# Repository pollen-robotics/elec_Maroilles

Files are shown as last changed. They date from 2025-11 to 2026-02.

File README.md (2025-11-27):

# "Maroilles" Electronic Board

"elec_maroilles" is USB 2.0 hub built with lockable USB connectors. It provides also Dynamixel TTL and Dynamixel RS485 converters and the associated connectors for Reachy 2's grippers and antennas.

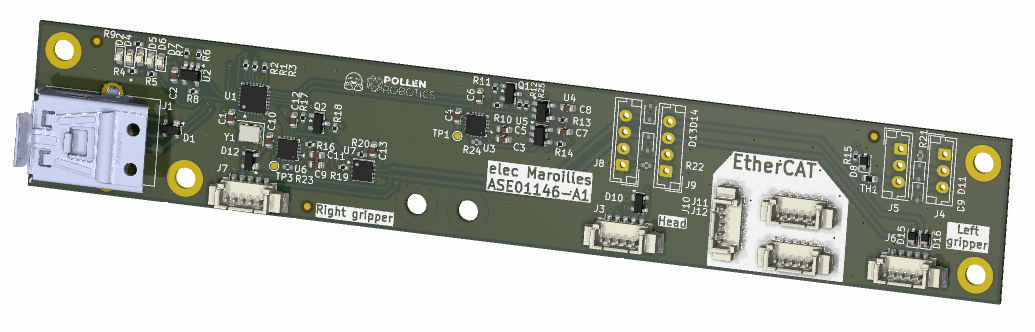
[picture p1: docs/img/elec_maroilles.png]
3d view


## Basically
 - Designed with KiCAD 9.

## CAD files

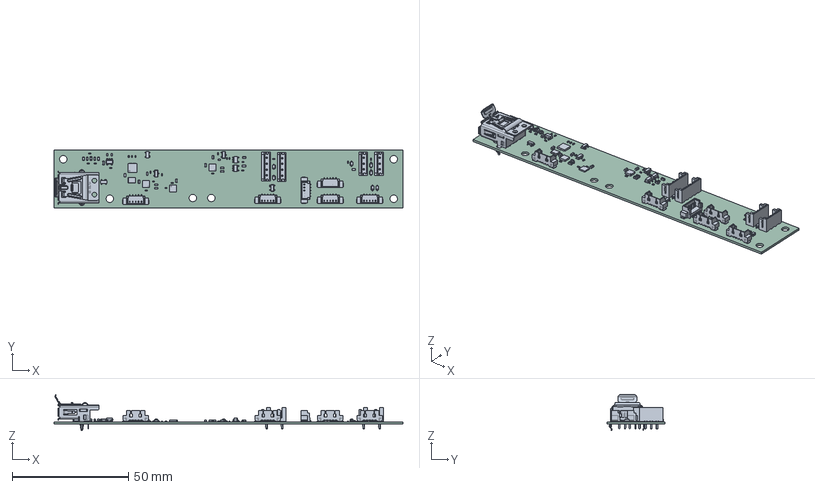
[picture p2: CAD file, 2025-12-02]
fab/elec_maroilles.step
150.0 x 25.0 x 15.6 mm
Molex_PicoBlade_53398-0571_1x05-1MP_P1.25mm_Vertical x 6
C_0603_1608Metric x 13
JST_EH_B3B-EH-A_1x03_P2.50mm_Vertical x 2
WQFN-16-1EP_3x3mm_P0.5mm_EP1.6x1.6mm x 3
R_0402_1005Metric x 25
LUSBA11100--3DModel-STEP-533217
R_0603_1608Metric
D_SOD-323 x 7
Texas_RTW_WQFN-24-1EP_4x4mm_P0.5mm_EP2.7x2.7mm
SOT-143 x 3
SOT-23-5 x 3
JST_EH_B4B-EH-A_1x04_P2.50mm_Vertical x 2
LED_0603_1608Metric x 5
SOT-23 x 2
Crystal_SMD_3225-4Pin_3.2x2.5mm
DFN-8-1EP_3x3mm_P0.65mm_EP1.5x2.25mm
elec_maroilles_PCB

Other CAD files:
fab/ASE01146-A1_elec_maroilles_STEP.step

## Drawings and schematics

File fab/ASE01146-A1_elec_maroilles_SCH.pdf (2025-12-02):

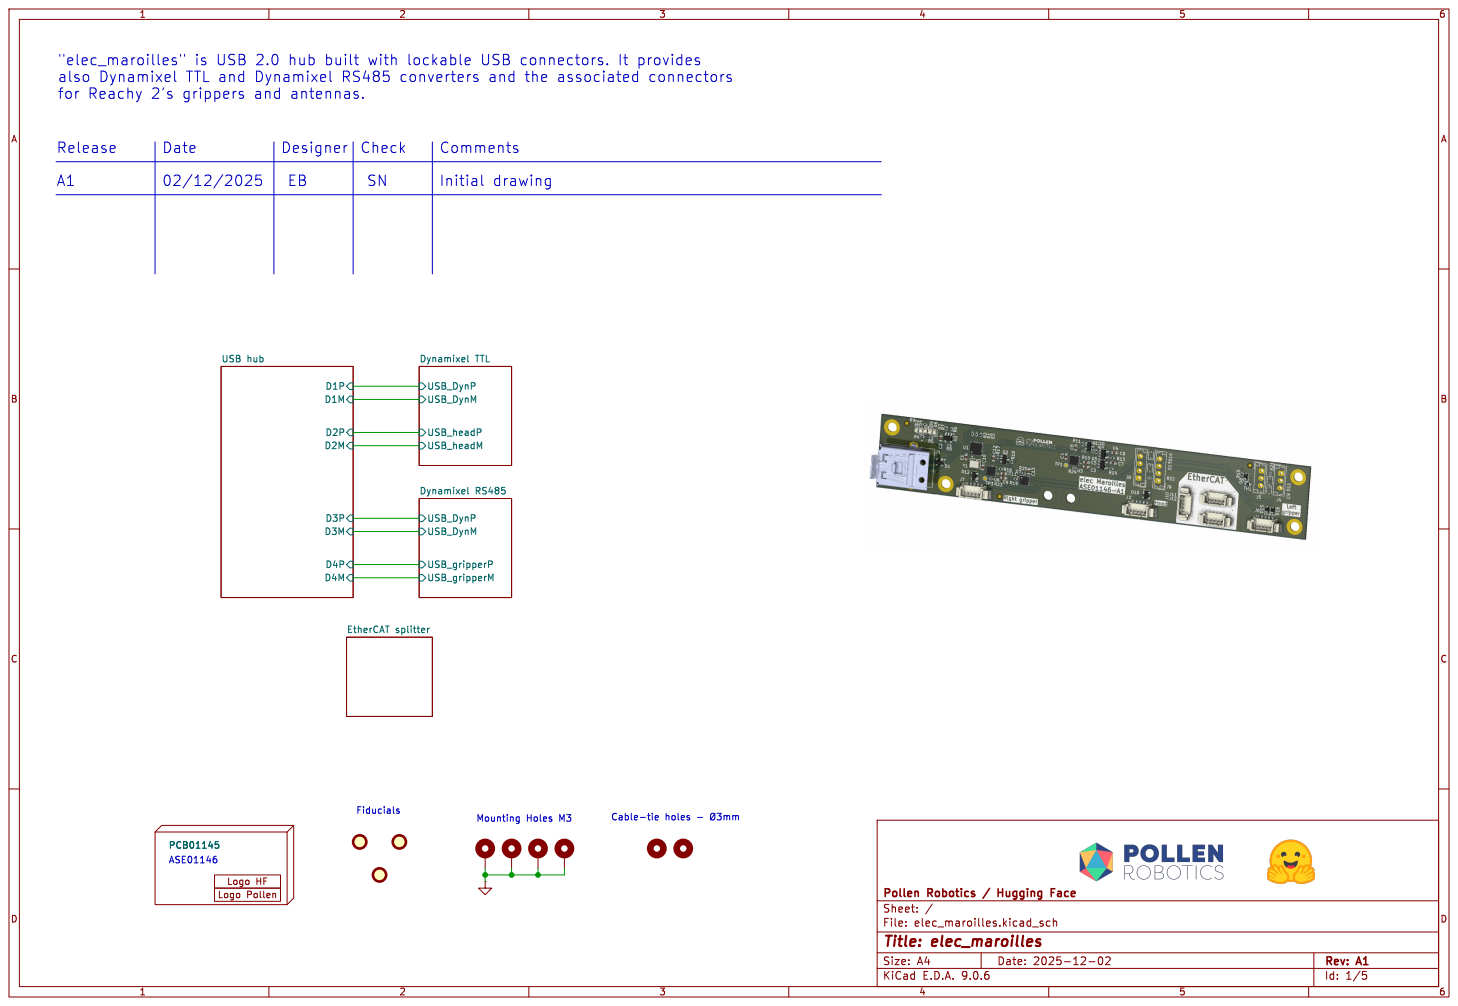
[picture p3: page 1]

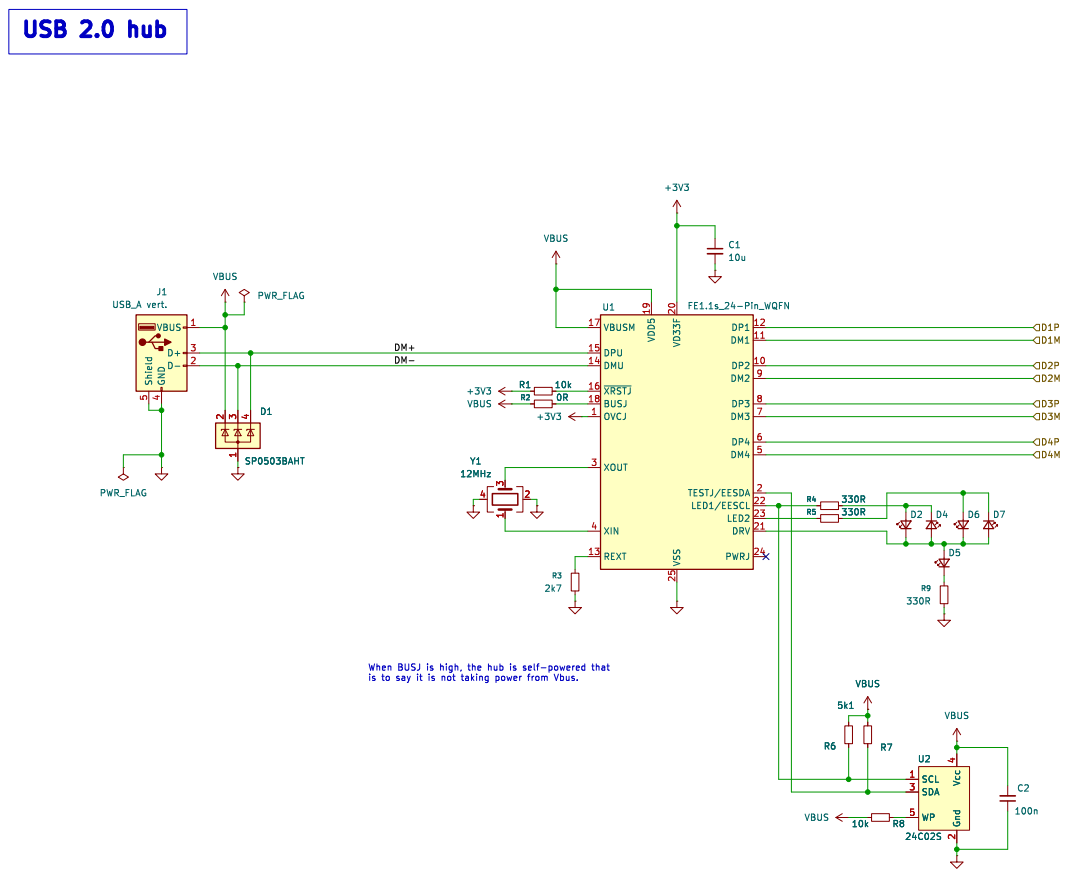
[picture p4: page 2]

DM+ DM- USB 2.0 hub

is to say it is not taking power from Vbus. D1 SP0503BAHT

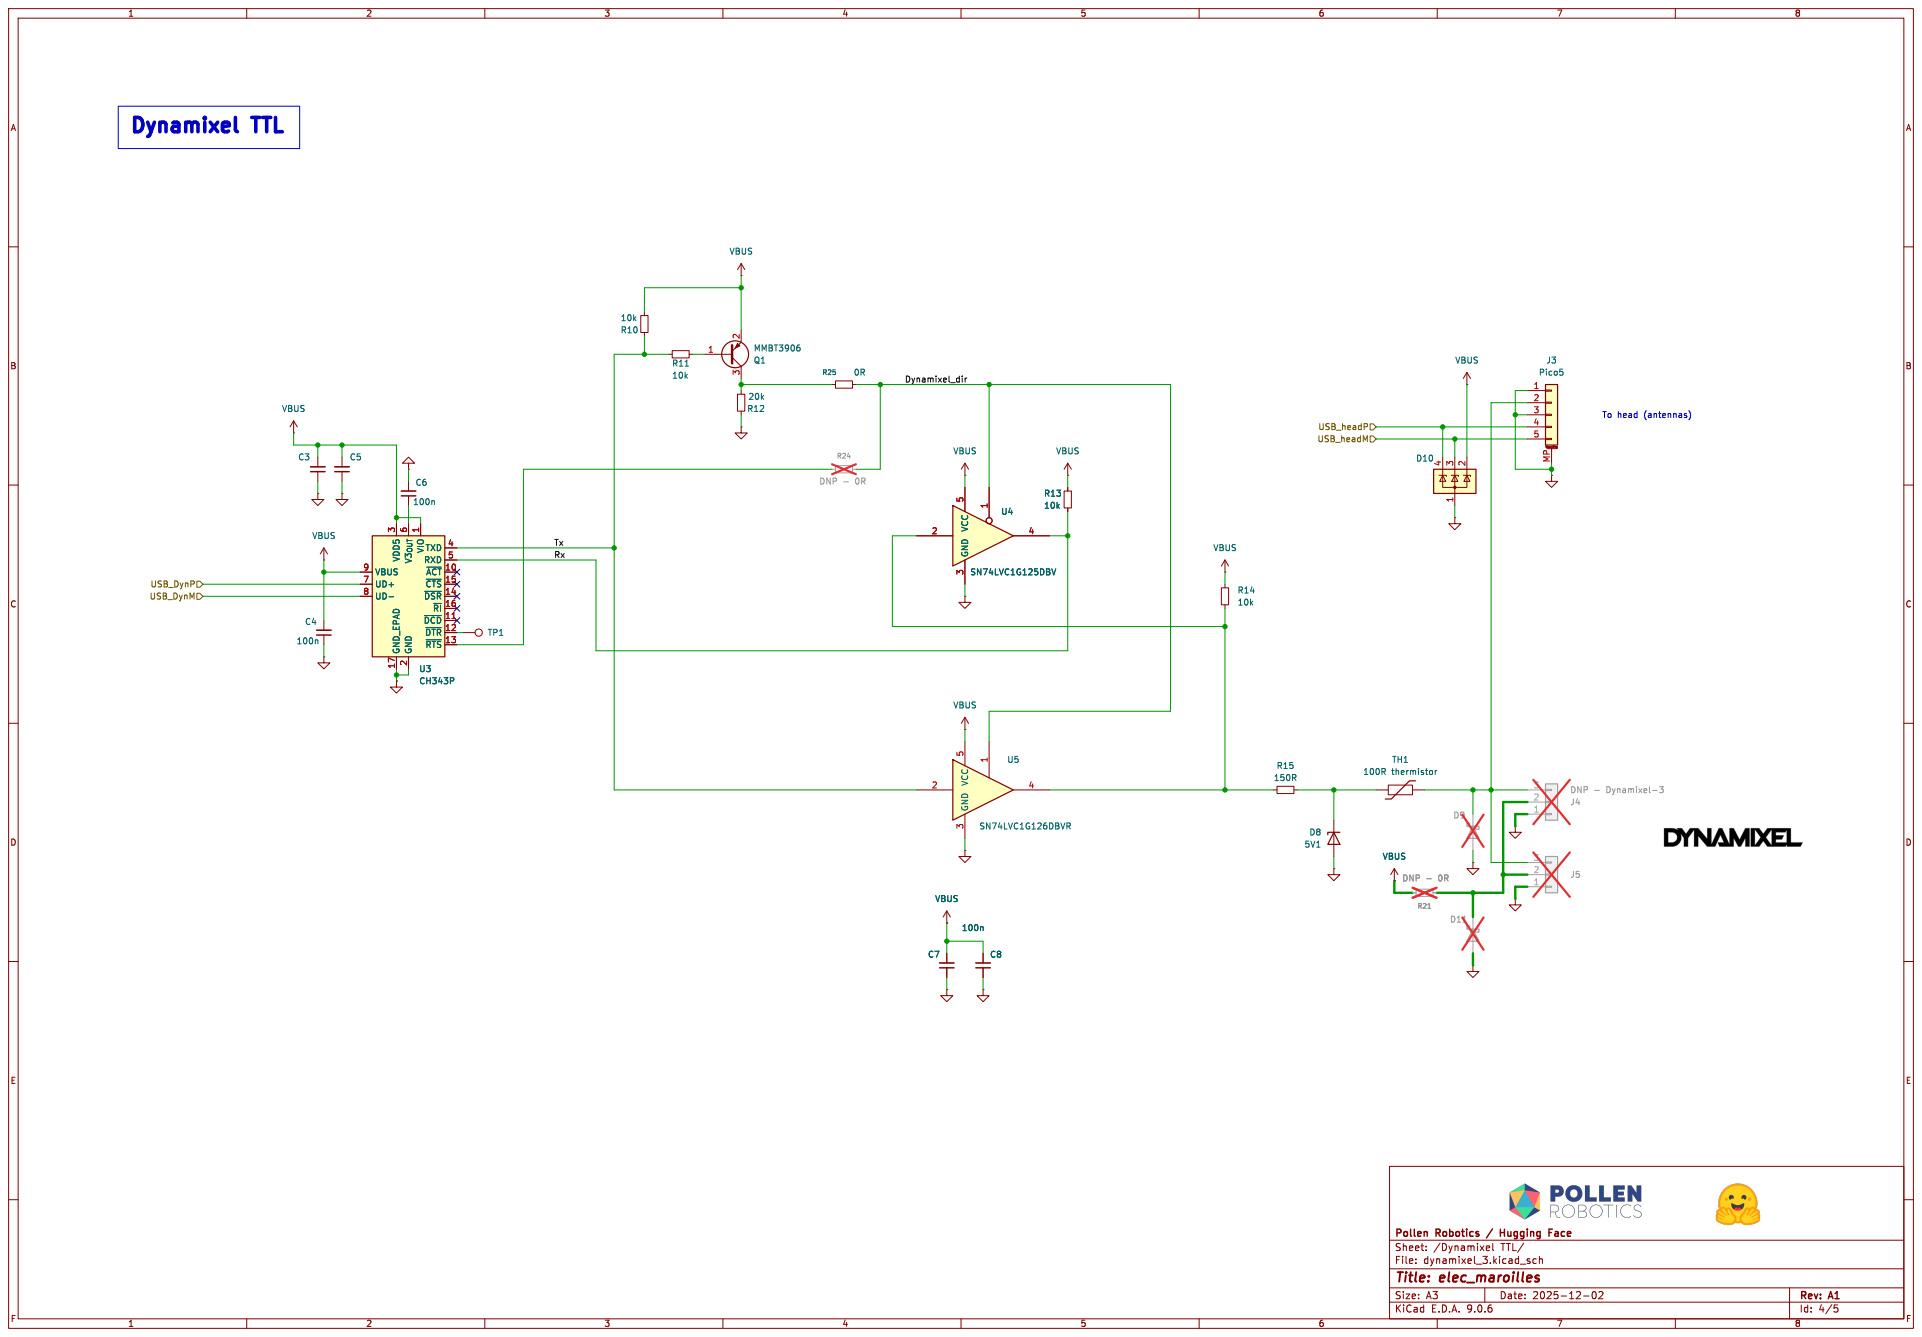
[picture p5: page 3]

1 TXD 4 RXD 5 ~{ACT} 10 ~{CTS} 15 ~{DSR} 14 ~{RI} 16 ~{DCD} 11 ~{DTR} 12 ~{RTS} 13 U3 CH343P

1 TXD 4 RXD 5 ~{ACT} 10 ~{CTS} 15 ~{DSR} 14 ~{RI} 16 ~{DCD} 11 ~{DTR} 12 ~{RTS} 13 VBUS C7

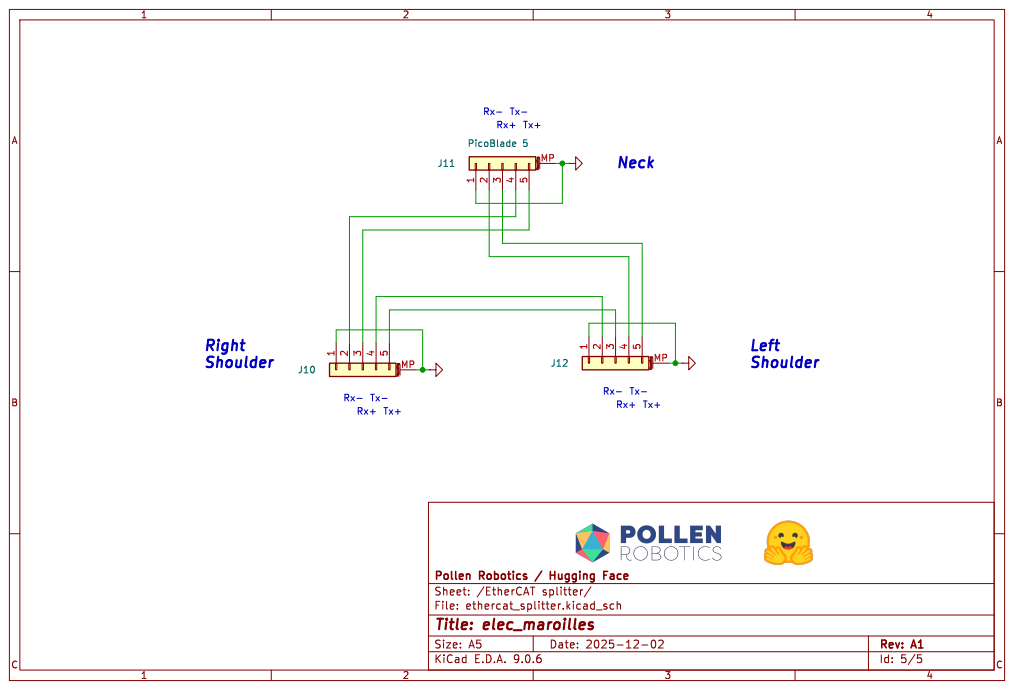
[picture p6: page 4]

5 MP J11 PicoBlade 5 Tx+ Tx+ Left

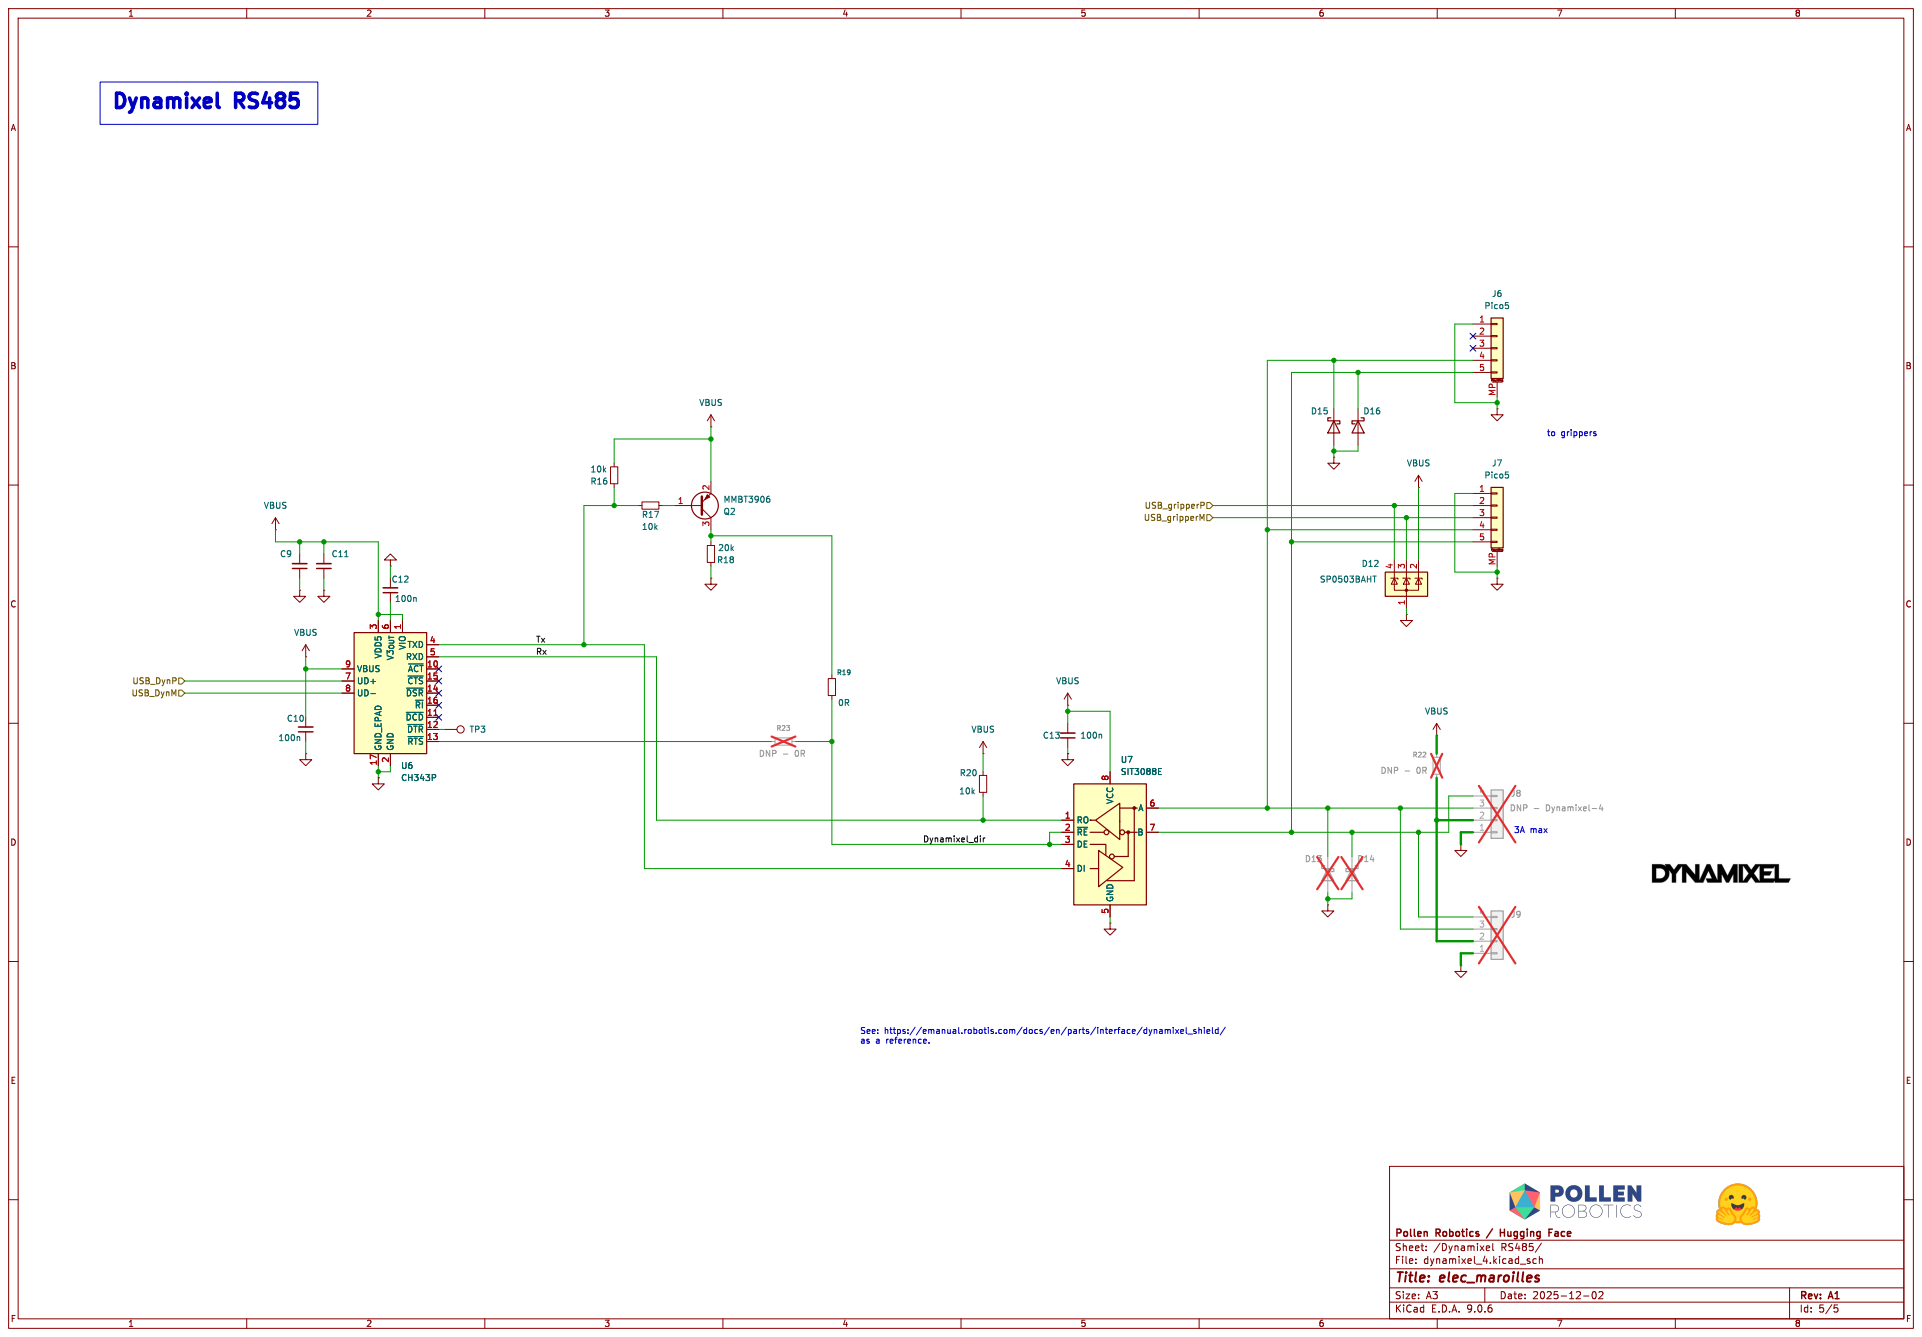
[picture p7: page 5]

1 TXD 4 RXD 5 ~{ACT} 10 ~{CTS} 15 ~{DSR} 14 ~{RI} 16 ~{DCD} 11 ~{DTR} 12 ~{RTS} 13 U6 CH343P D13 D14 USB_gripperP

1 TXD 4 RXD 5 ~{ACT} 10 ~{CTS} 15 ~{DSR} 14 ~{RI} 16 ~{DCD} 11 ~{DTR} 12 ~{RTS} 13 U7SIT3088E RO 1 ~{RE} 2 DE 3 DI 4 VCC

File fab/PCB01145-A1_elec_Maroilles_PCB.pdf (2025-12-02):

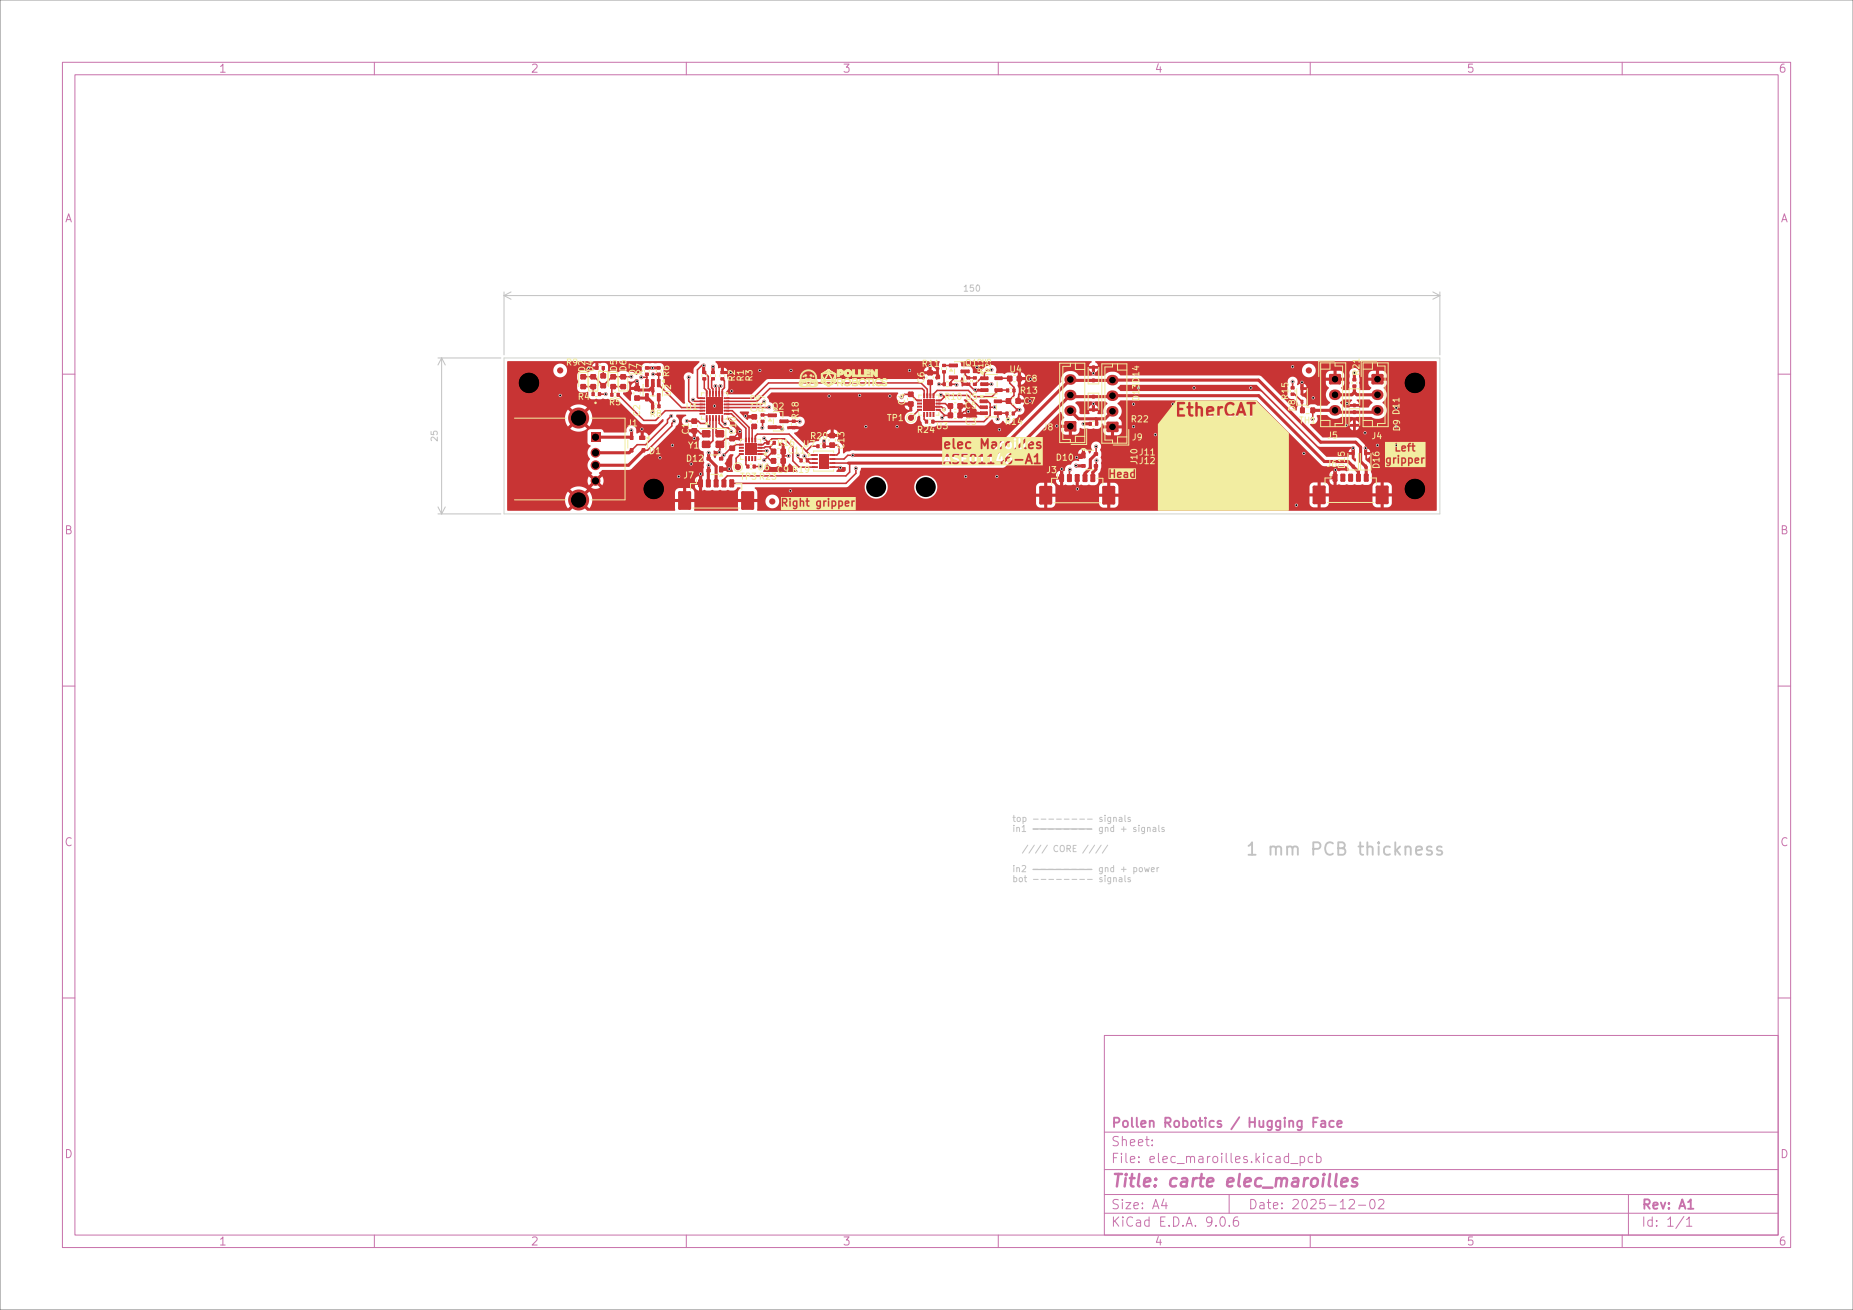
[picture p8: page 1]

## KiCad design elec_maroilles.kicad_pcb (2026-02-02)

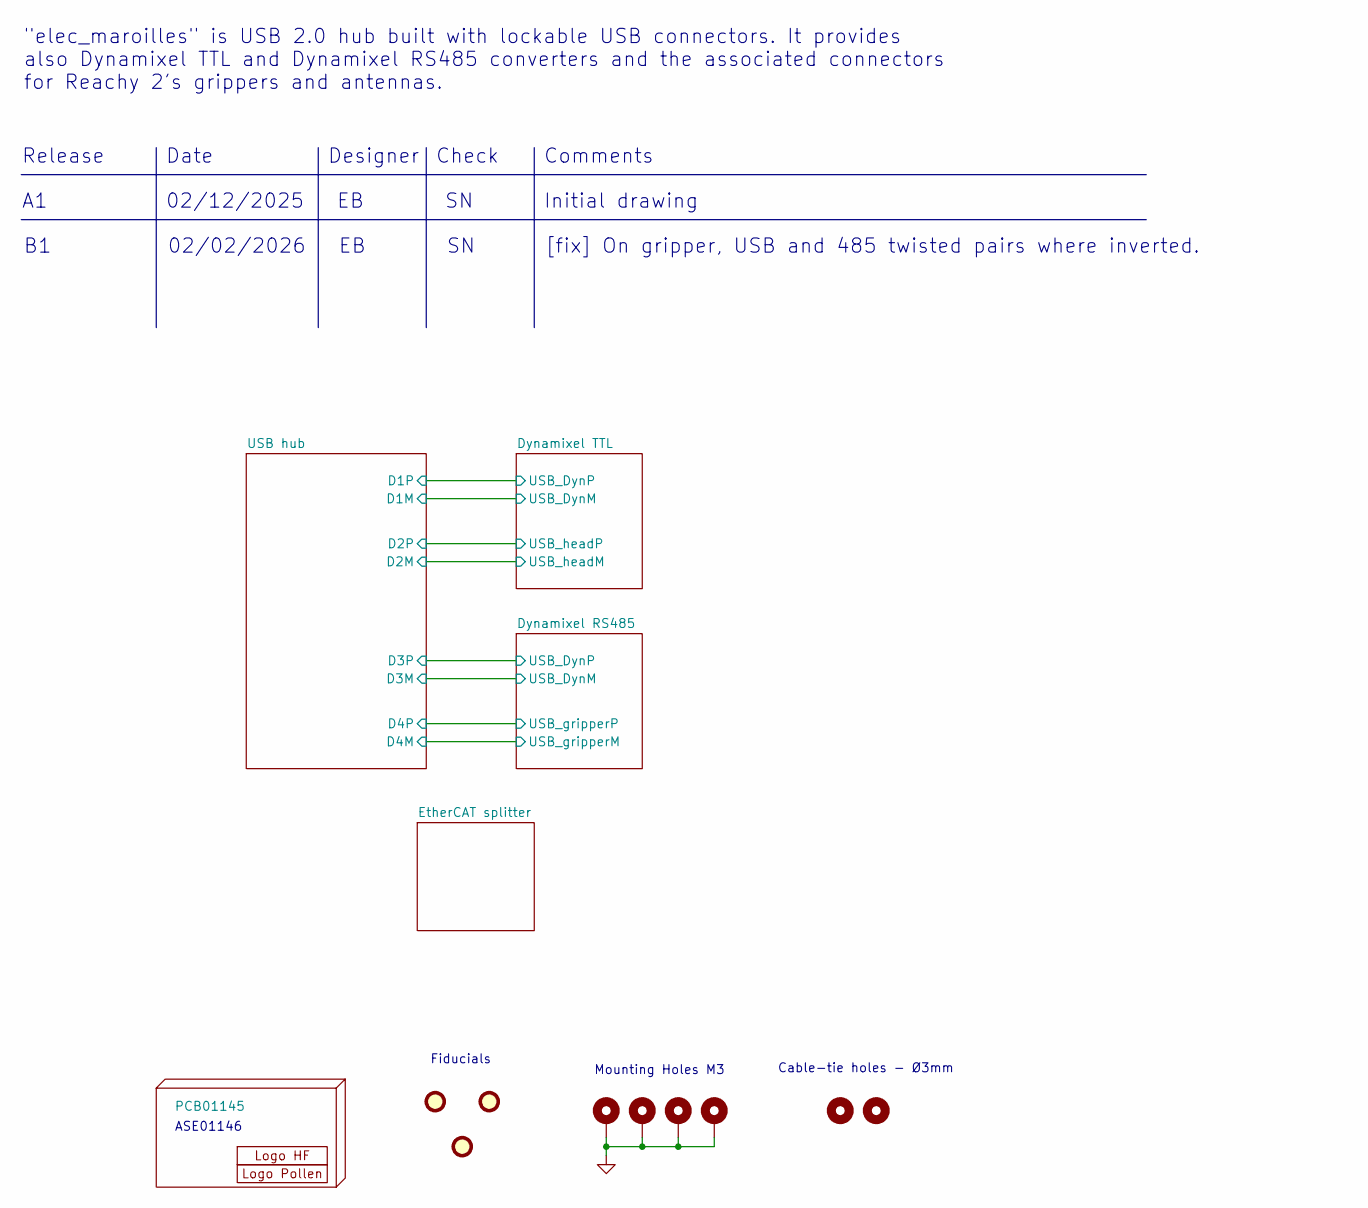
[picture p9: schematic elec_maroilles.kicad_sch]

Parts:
FID1, FID2, FID3: DNP Fiducial; Fiducial_1mm_Mask2mm
H1: PCB01145
H2: Logo HF 2025; Logo_HF_2025
H3: DNP Logo Pollen 2021; Logo_Pollen_2021_sq
H4, H5, H6, H7: MountingHole_Pad; MountingHole_3.2mm_M3_ISO7380_Pad_TopBottom
H10, H11: MountingHole_Pad; MountingHole_3.2mm_M3

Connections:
GND: H4.1, H5.1, H6.1, H7.1; also elsewhere on the board

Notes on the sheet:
Mounting Holes M3
Date
Check
Release
Fiducials
ASE01146
Cable-tie holes - Ø3mm
Initial drawing
[fix] On gripper, USB and 485 twisted pairs where inverted.
"elec_maroilles" is USB 2.0 hub built with lockable USB connectors. It provides also Dynamixel TTL and Dynamixel RS485 converters and the associated connectors for Reachy 2's grippers and antennas.
02/02/2026
Designer
Comments
02/12/2025

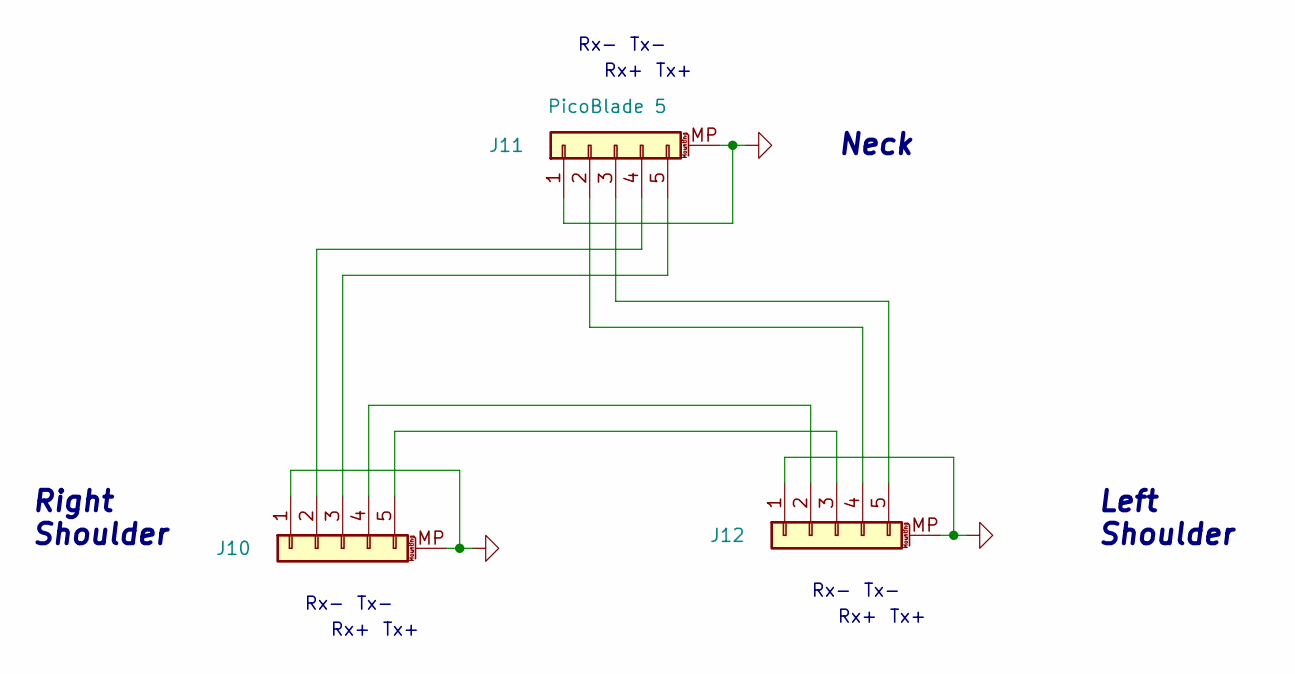
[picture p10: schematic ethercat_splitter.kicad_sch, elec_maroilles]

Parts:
J10, J11, J12: PicoBlade 5; Molex_PicoBlade_53398-0571_1x05-1MP_P1.25mm_Vertical; LCSC Part C504986

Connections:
GND: J10.1, J10.MP (MountPin), J11.1, J11.MP (MountPin), J12.1, J12.MP (MountPin); also elsewhere on the board
unnamed: J10.2, J11.4
unnamed: J10.3, J11.5
unnamed: J10.4, J12.2
unnamed: J10.5, J12.3
unnamed: J11.2, J12.4
unnamed: J11.3, J12.5

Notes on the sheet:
Rx-
Tx-
Right Shoulder
Rx+
Left Shoulder
Neck
Tx+

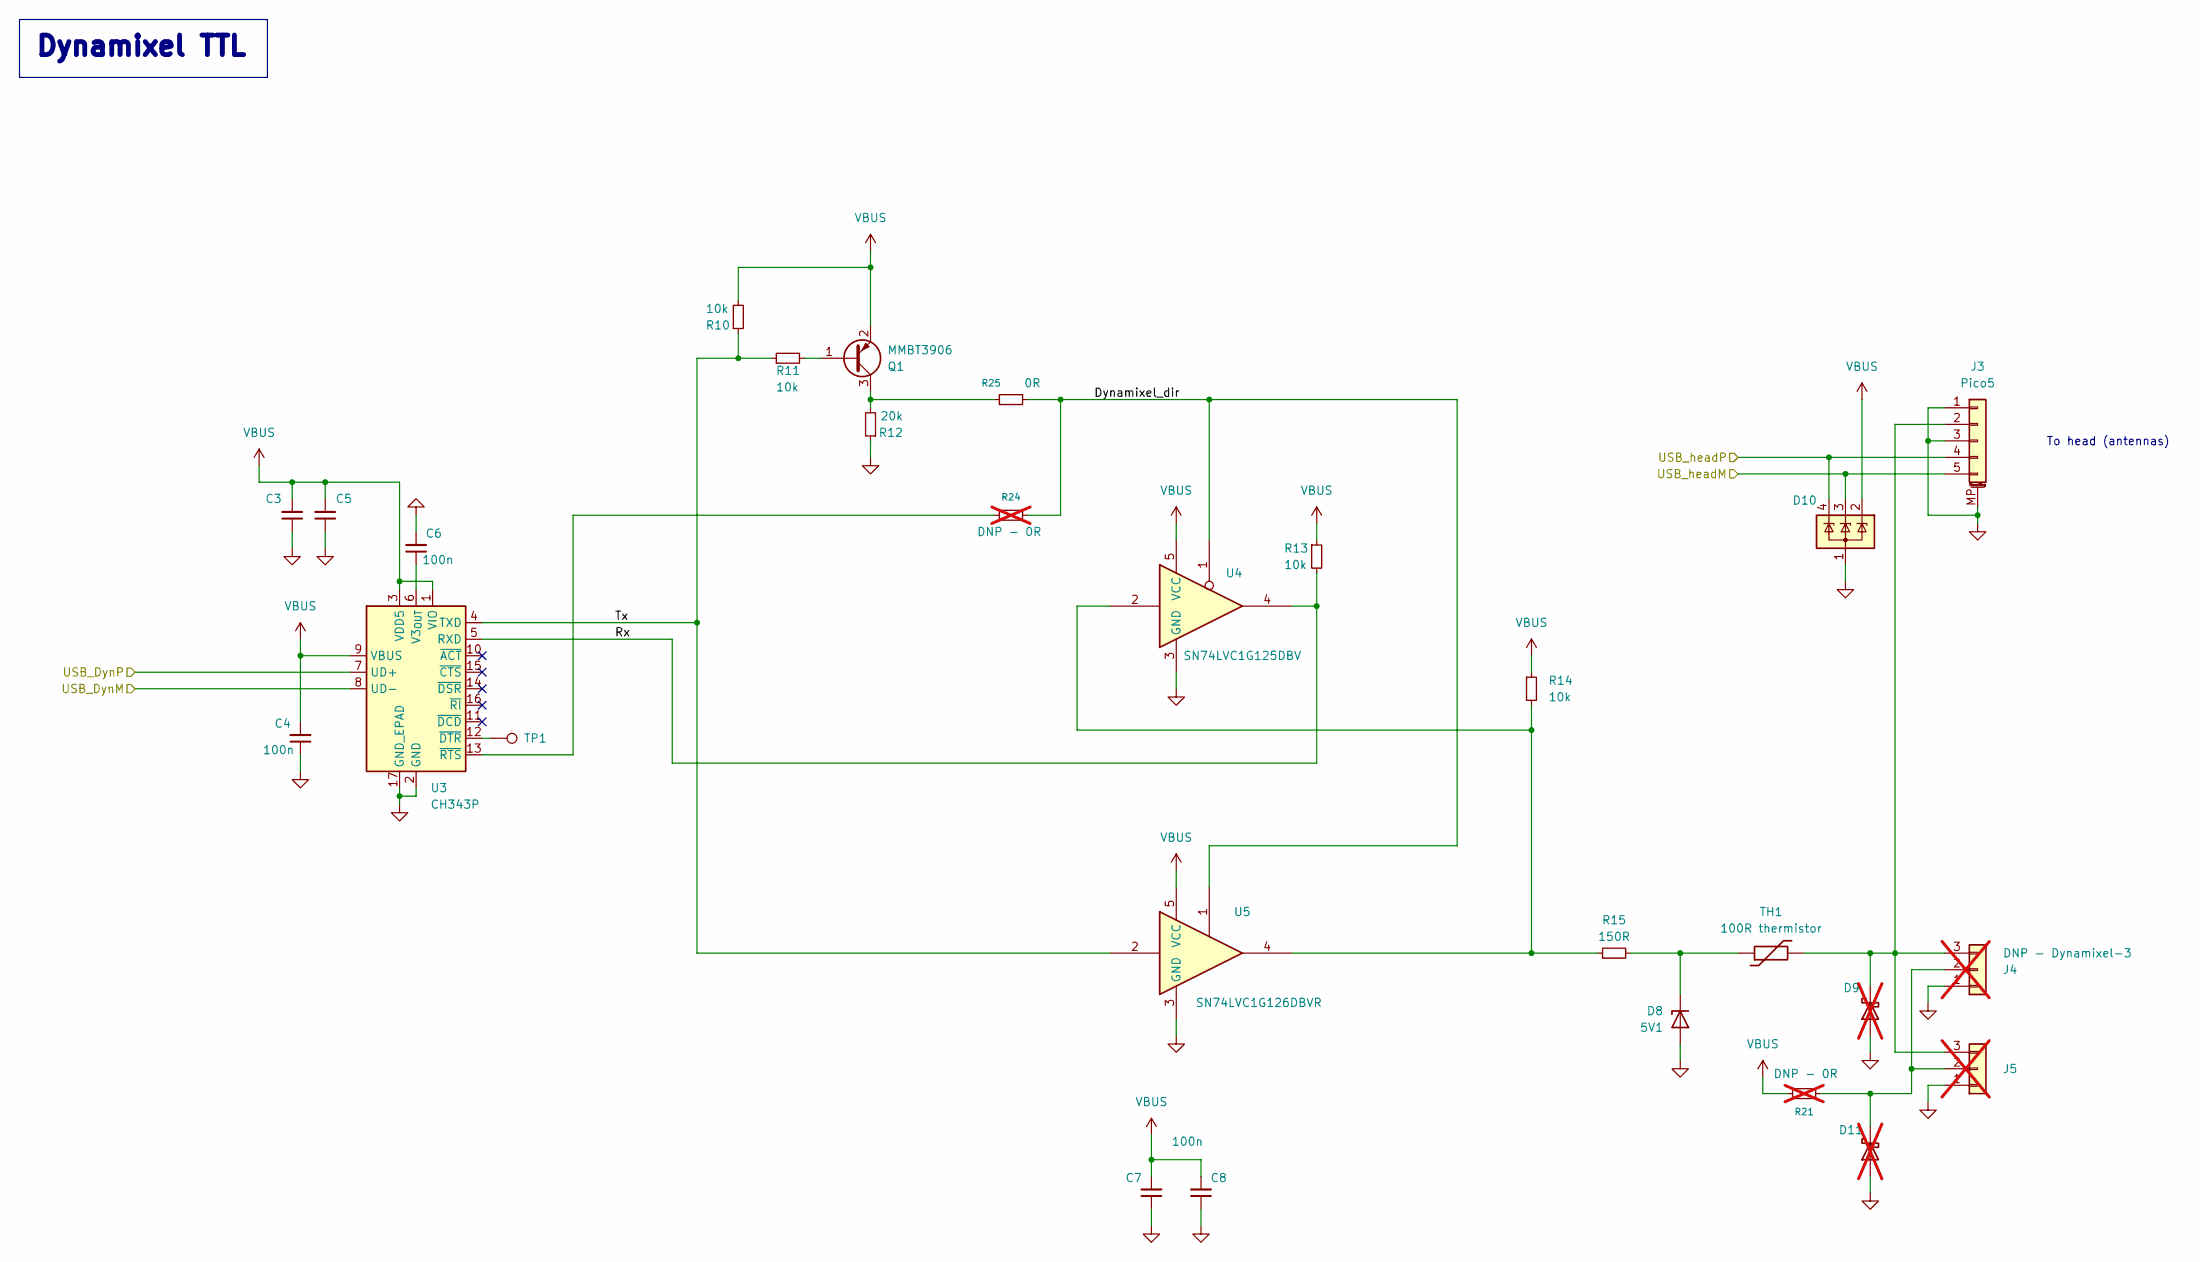
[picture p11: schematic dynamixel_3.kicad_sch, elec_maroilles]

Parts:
C3, C5: 1uF-6V3; C_0603_1608Metric; LCSC Part C1592
C4, C6, C7, C8: 100n; C_0603_1608Metric; LCSC Part C85864
D8: 5V1; D_SOD-323; LCSC Part C151348
D9, D11: DNP - B5819WS; D_SOD-323; LCSC Part C78734; not fitted
D10: SP0503BAHT; SOT-143; LCSC Part C41364459
J3: Pico5; Molex_PicoBlade_53398-0571_1x05-1MP_P1.25mm_Vertical; LCSC Part C504986
J4, J5: DNP - Dynamixel-3; JST_EH_B3B-EH-A_1x03_P2.50mm_Vertical; LCSC Part C160259; not fitted
Q1: MMBT3906; SOT-23; LCSC Part C727128
R10, R11, R13, R14: 10k; R_0402_1005Metric; LCSC Part C25744
R12: 20k; R_0402_1005Metric; LCSC Part C2906867
R15: 150R; R_0402_1005Metric; LCSC Part C138054
R21: DNP - 0R; R_0402_1005Metric; not fitted
R24: DNP - 0R; R_0402_1005Metric; LCSC Part C17168; not fitted
R25: 0R; R_0402_1005Metric; LCSC Part C17168
TH1: 100R thermistor; R_0603_1608Metric; LCSC Part C913703
TP1: TestPoint; TestPoint_Pad_D1.0mm
U3: CH343P; WCH_QFN-16-1EP_3x3mm_P0.5mm_EP1.8x1.8mm; LCSC Part C2846043
U4: SN74LVC1G125DBV; SOT-23-5; LCSC Part C23654
U5: SN74LVC1G126DBVR; SOT-23-5; LCSC Part C7834

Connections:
/Dynamixel TTL/Dynamixel_dir: R24.2, R25.2, U4.1, U5.1
/Dynamixel TTL/Rx: R13.2, U3.5 (RXD), U4.4
/Dynamixel TTL/Tx: R10.1, R11.1, U3.4 (TXD), U5.2
/Dynamixel TTL/USB_DynM: U3.8 (UD-); also elsewhere on the board
/Dynamixel TTL/USB_DynP: U3.7 (UD+); also elsewhere on the board
/Dynamixel TTL/USB_headM: D10.3 (K), J3.5; also elsewhere on the board
/Dynamixel TTL/USB_headP: D10.4 (K), J3.4; also elsewhere on the board
GND: C3.1, C4.1, C5.1, C6.2, C7.1, C8.1, D8.2 (A), D9.2 (A), D10.1 (A), D11.2 (A), J3.1, J3.3, J3.MP (MountPin), J4.1, J5.1, R12.1, U3.2 (GND), U3.17 (GND_EPAD), U4.3 (GND), U5.3 (GND); also elsewhere on the board
unnamed: D8.1 (K), R15.2, TH1.1
unnamed: D9.1 (K), J3.2, J4.3, J5.3, TH1.2
unnamed: D11.1 (K), J4.2, J5.2, R21.2
unnamed: Q1.1 (B), R11.2
unnamed: Q1.3 (C), R12.2, R25.1
unnamed: R14.2, R15.1, U4.2, U5.4
unnamed: C6.1, U3.6 (V3_{OUT})
unnamed: TP1.1, U3.12 (~DTR)
unnamed: R24.1, U3.13 (~RTS)
VBUS: C3.2, C4.2, C5.2, C7.2, C8.2, D10.2 (K), Q1.2 (E), R10.2, R13.1, R14.1, R21.1, U3.1 (VIO), U3.3 (VDD5), U3.9 (VBUS), U4.5 (VCC), U5.5 (VCC); also elsewhere on the board

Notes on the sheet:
To head (antennas)
Dynamixel TTL

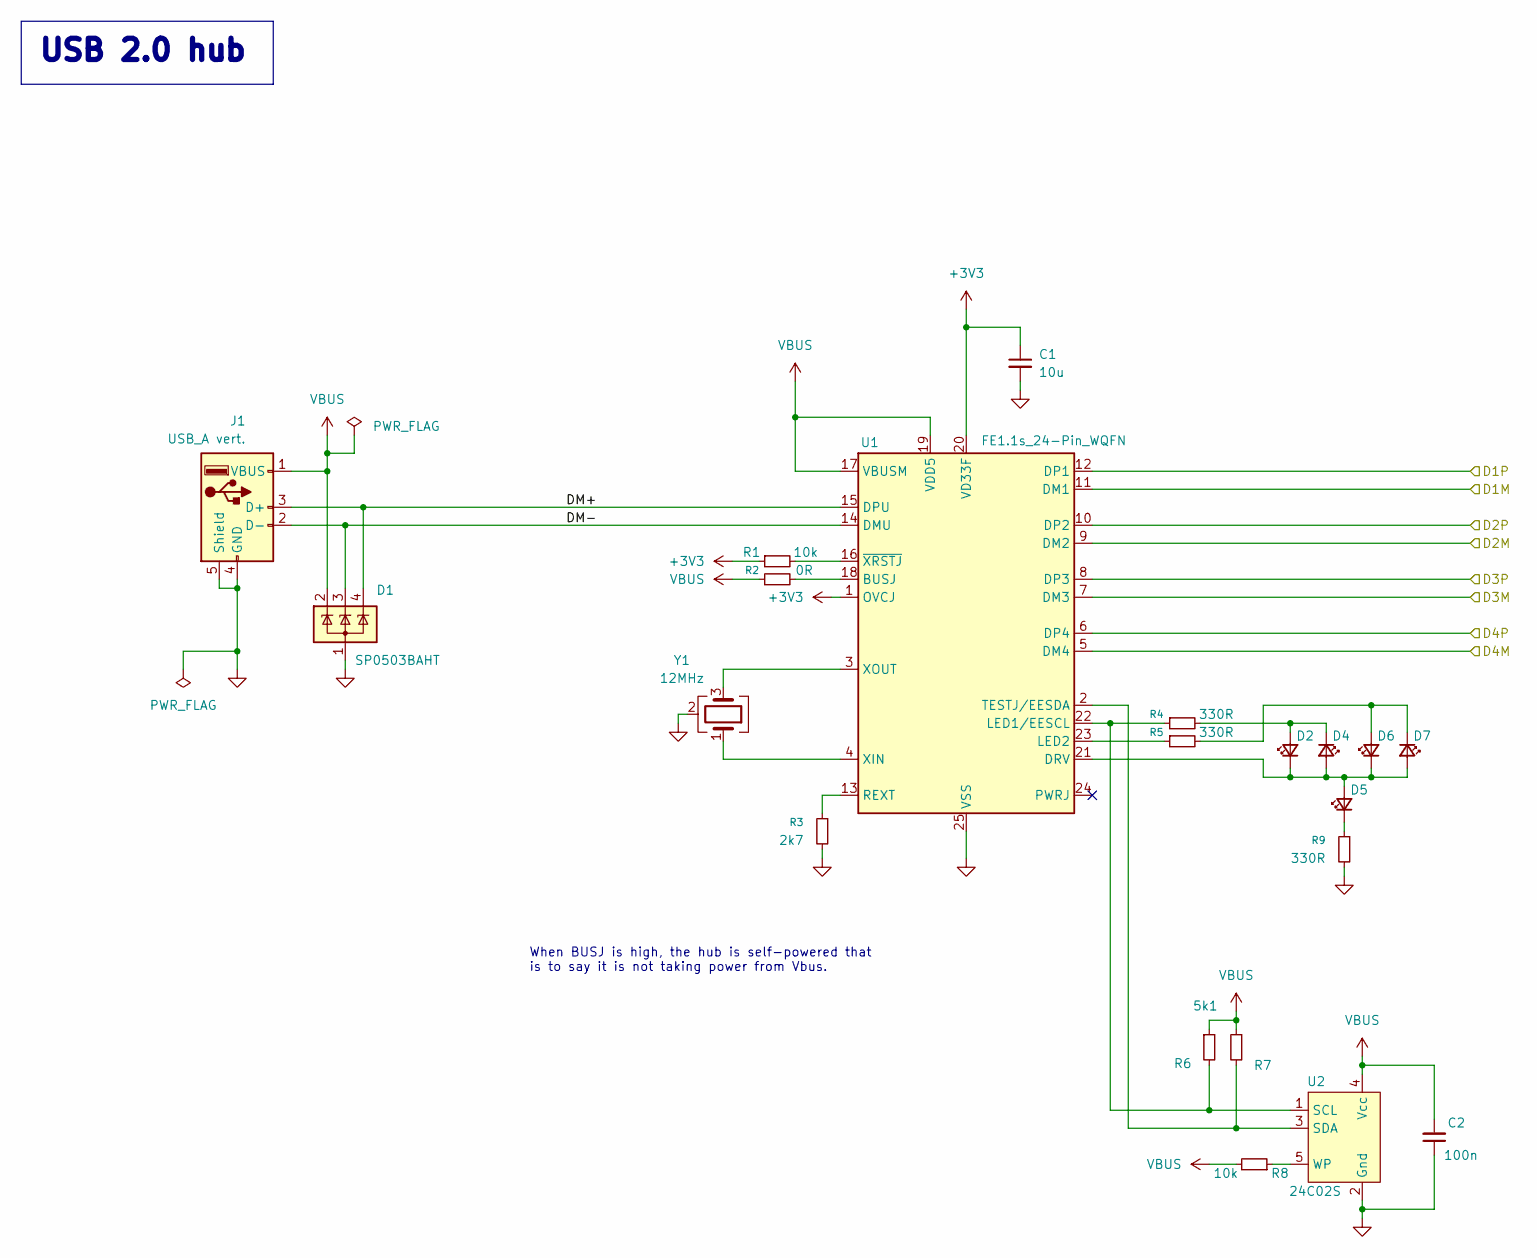
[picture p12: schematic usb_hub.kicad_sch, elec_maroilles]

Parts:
C1: 10u; C_0603_1608Metric; LCSC Part C1691
C2: 100n; C_0603_1608Metric; LCSC Part C85864
D1: SP0503BAHT; SOT-143; LCSC Part C41364459
D2, D6: LED_Small; LED_0603_1608Metric; LCSC Part C19171301
D4, D7: LED_Small; LED_0603_1608Metric; LCSC Part C84263
D5: LED_Small; LED_0603_1608Metric; LCSC Part C7429915
J1: USB_A vert.; Amphenol_LUSBA11100; LCSC Part C3197751
R1, R8: 10k; R_0402_1005Metric; LCSC Part C25744
R2: 0R; R_0402_1005Metric; LCSC Part C17168
R3: 2k7; R_0402_1005Metric; LCSC Part C138017
R4, R5, R9: 330R; R_0402_1005Metric; LCSC Part C105875
R6, R7: 5k1; R_0402_1005Metric; LCSC Part C25905
U1: FE1.1s_24-Pin_WQFN; WQFN-24-1EP_4x4mm_P0.5mm_EP2.6x2.6mm; LCSC Part C6776948
U2: 24C02S; SOT-23-5; LCSC Part C18723540
Y1: 12MHz; Crystal_SMD_3225-4Pin_3.2x2.5mm; LCSC Part C133334

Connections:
+3V3: C1.1, R1.1, U1.1 (OVCJ), U1.20 (VD33F)
/Dynamixel RS485/USB_DynM: U1.7 (DM3); also elsewhere on the board
/Dynamixel RS485/USB_DynP: U1.8 (DP3); also elsewhere on the board
/Dynamixel RS485/USB_gripperM: U1.5 (DM4); also elsewhere on the board
/Dynamixel RS485/USB_gripperP: U1.6 (DP4); also elsewhere on the board
/Dynamixel TTL/USB_DynM: U1.11 (DM1); also elsewhere on the board
/Dynamixel TTL/USB_DynP: U1.12 (DP1); also elsewhere on the board
/Dynamixel TTL/USB_headM: U1.9 (DM2); also elsewhere on the board
/Dynamixel TTL/USB_headP: U1.10 (DP2); also elsewhere on the board
/USB hub/DM+: D1.4 (K), J1.3 (D+), U1.15 (DPU)
/USB hub/DM-: D1.3 (K), J1.2 (D-), U1.14 (DMU)
GND: C1.2, C2.1, D1.1 (A), J1.4 (GND), J1.5 (Shield), R3.2, R9.2, U1.25 (VSS), U2.2 (Gnd), Y1.2 (G), Y1.4 (G); also elsewhere on the board
unnamed: D2.2 (A), D4.1 (K), R4.2
unnamed: D2.1 (K), D4.2 (A), D5.2 (A), D6.1 (K), D7.2 (A), U1.21 (DRV)
unnamed: D5.1 (K), R9.1
unnamed: D6.2 (A), D7.1 (K), R5.2
unnamed: R2.2, U1.18 (BUSJ)
unnamed: R4.1, R6.2, U1.22 (LED1/EESCL), U2.1 (SCL)
unnamed: R5.1, U1.23 (LED2)
unnamed: R3.1, U1.13 (REXT)
unnamed: R7.2, U1.2 (TESTJ/EESDA), U2.3 (SDA)
unnamed: U1.4 (XIN), Y1.1
unnamed: U1.3 (XOUT), Y1.3
unnamed: R1.2, U1.16 (~XRSTJ)
unnamed: R8.1, U2.5 (WP)
VBUS: C2.2, D1.2 (K), J1.1 (VBUS), R2.1, R6.1, R7.1, R8.2, U1.17 (VBUSM), U1.19 (VDD5), U2.4 (Vcc); also elsewhere on the board

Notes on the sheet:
When BUSJ is high, the hub is self-powered that is to say it is not taking power from Vbus.
USB 2.0 hub

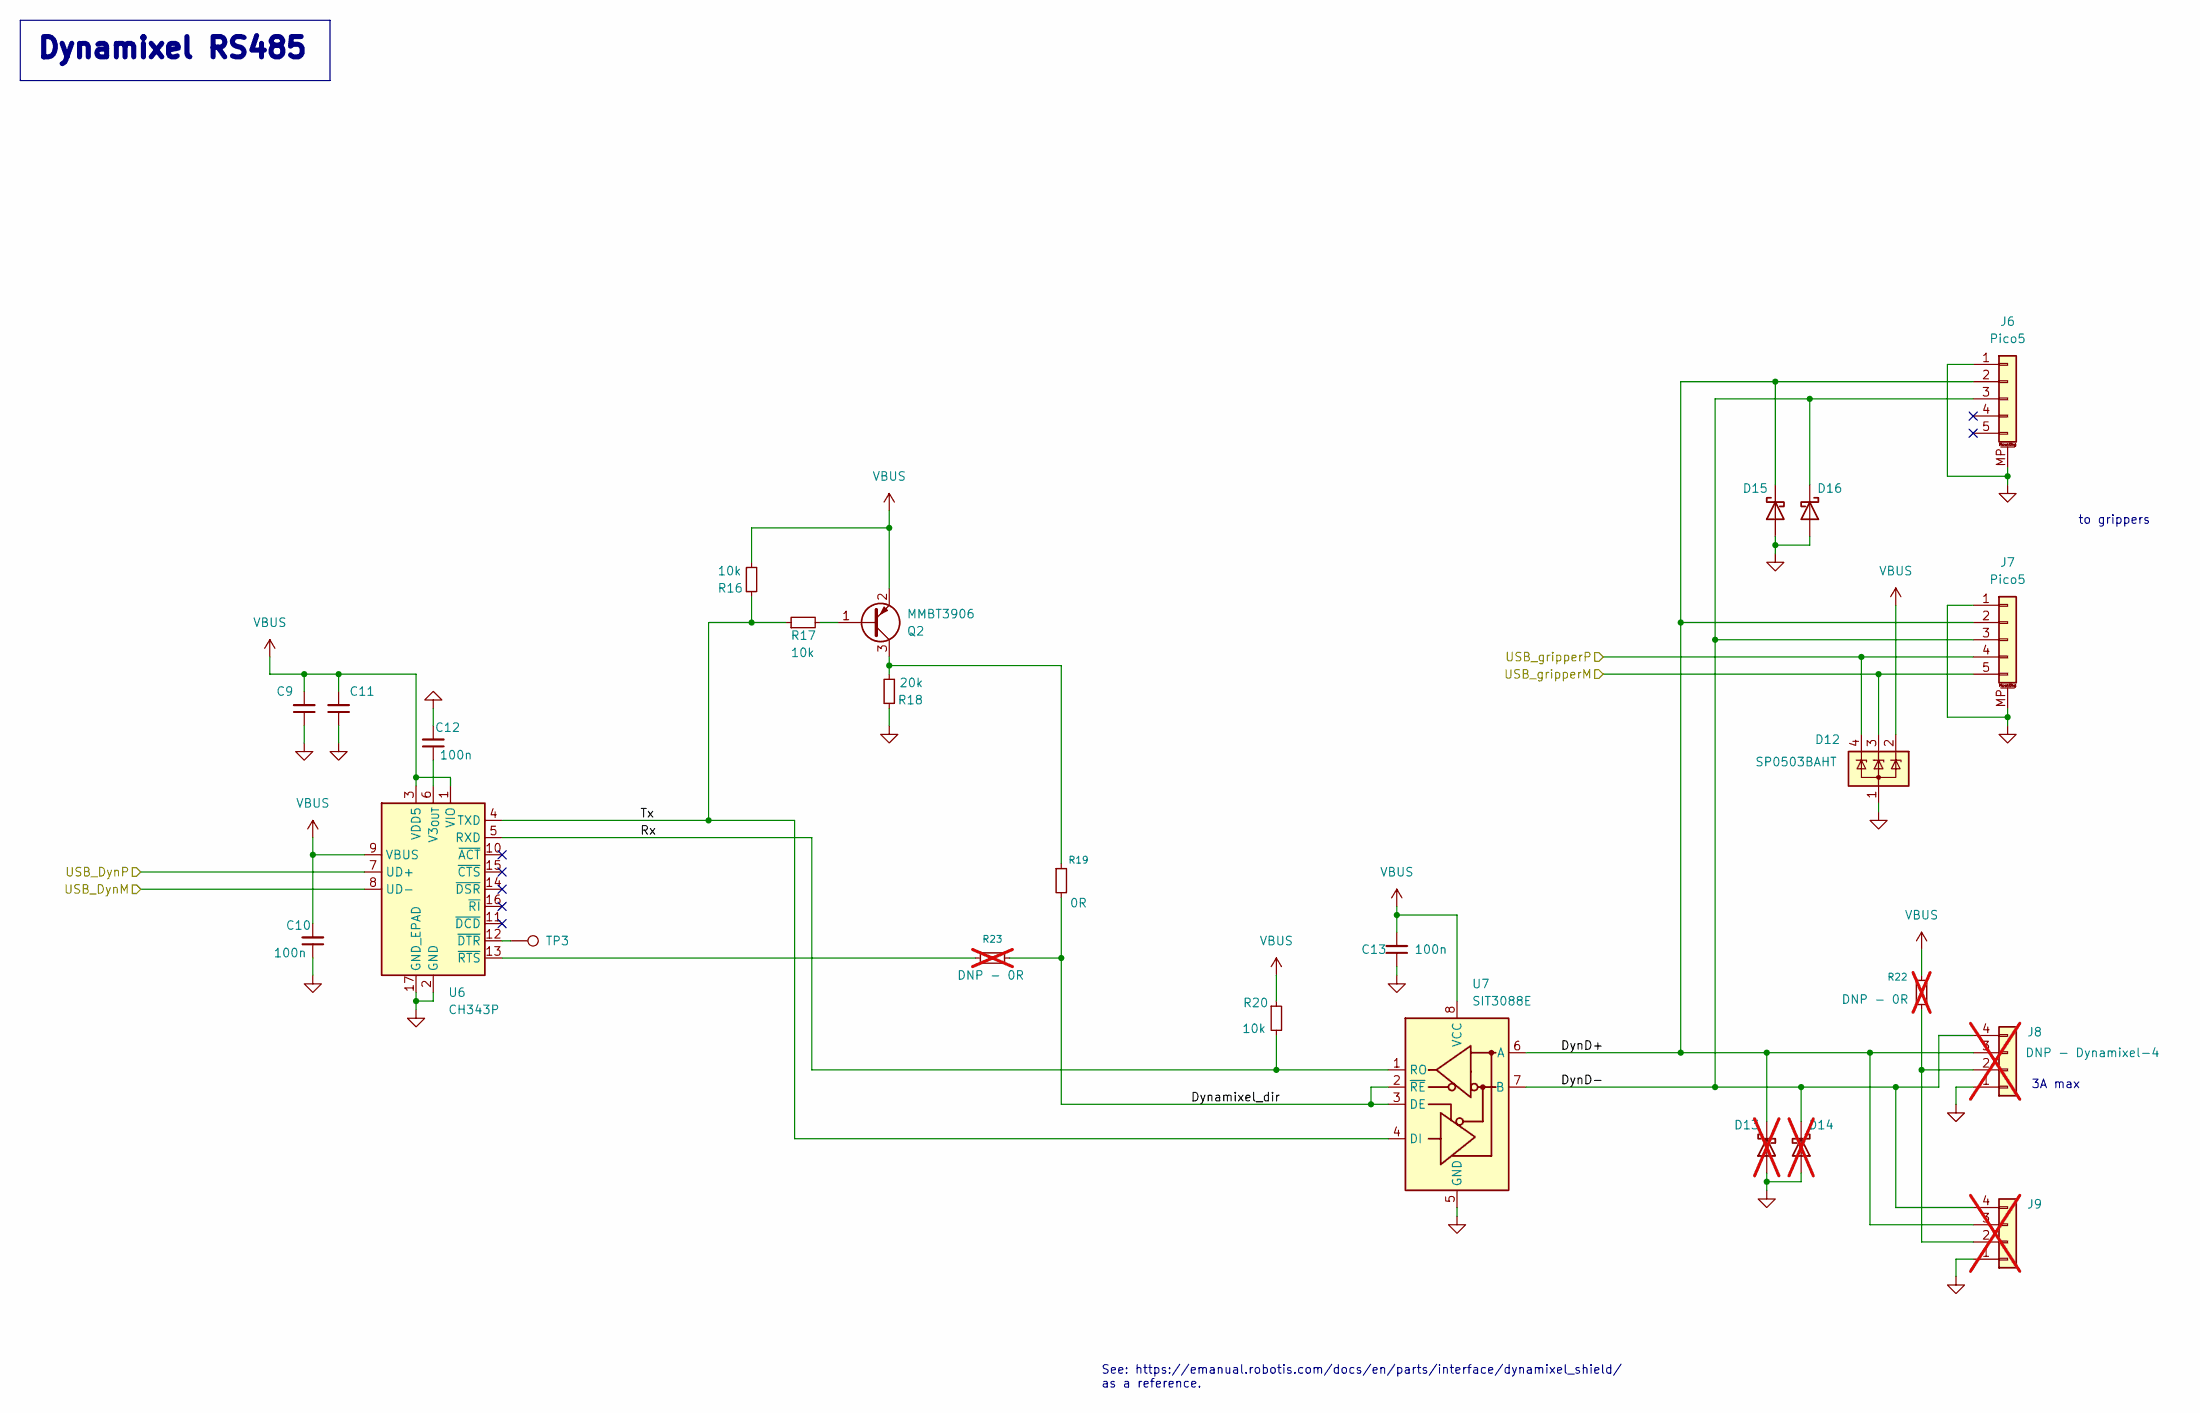
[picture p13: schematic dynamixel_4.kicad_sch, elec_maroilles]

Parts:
C9, C11: 1uF-6V3; C_0603_1608Metric; LCSC Part C1592
C10, C12, C13: 100n; C_0603_1608Metric; LCSC Part C85864
D12: SP0503BAHT; SOT-143; LCSC Part C41364459
D13, D14: DNP - B5819WS; D_SOD-323; LCSC Part C78734; not fitted
D15, D16: B5819WS; D_SOD-323; LCSC Part C78734
J6, J7: Pico5; Molex_PicoBlade_53398-0571_1x05-1MP_P1.25mm_Vertical; LCSC Part C504986
J8, J9: DNP - Dynamixel-4; JST_EH_B4B-EH-A_1x04_P2.50mm_Vertical; LCSC Part C160258; not fitted
Q2: MMBT3906; SOT-23; LCSC Part C727128
R16, R17, R20: 10k; R_0402_1005Metric; LCSC Part C25744
R18: 20k; R_0402_1005Metric; LCSC Part C2906867
R19: 0R; R_0402_1005Metric; LCSC Part C17168
R22: DNP - 0R; R_0402_1005Metric; not fitted
R23: DNP - 0R; R_0402_1005Metric; LCSC Part C17168; not fitted
TP3: TestPoint; TestPoint_Pad_D1.0mm
U6: CH343P; WCH_QFN-16-1EP_3x3mm_P0.5mm_EP1.8x1.8mm; LCSC Part C2846043
U7: SIT3088E; DFN-8-1EP_3x3mm_P0.65mm_EP1.5x2.25mm; LCSC Part C601076

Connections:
/Dynamixel RS485/DynD+: D13.1 (K), D15.1 (K), J6.2, J7.2, J8.3, J9.3, U7.6 (A)
/Dynamixel RS485/DynD-: D14.1 (K), D16.1 (K), J6.3, J7.3, J8.4, J9.4, U7.7 (B)
/Dynamixel RS485/Dynamixel_dir: R19.2, R23.2, U7.2 (~RE), U7.3 (DE)
/Dynamixel RS485/Rx: R20.2, U6.5 (RXD), U7.1 (RO)
/Dynamixel RS485/Tx: R16.1, R17.1, U6.4 (TXD), U7.4 (DI)
/Dynamixel RS485/USB_DynM: U6.8 (UD-); also elsewhere on the board
/Dynamixel RS485/USB_DynP: U6.7 (UD+); also elsewhere on the board
/Dynamixel RS485/USB_gripperM: D12.3 (K), J7.5; also elsewhere on the board
/Dynamixel RS485/USB_gripperP: D12.4 (K), J7.4; also elsewhere on the board
GND: C9.1, C10.1, C11.1, C12.2, C13.1, D12.1 (A), D13.2 (A), D14.2 (A), D15.2 (A), D16.2 (A), J6.1, J6.MP (MountPin), J7.1, J7.MP (MountPin), J8.1, J9.1, R18.1, U6.2 (GND), U6.17 (GND_EPAD), U7.5 (GND); also elsewhere on the board
unnamed: J8.2, J9.2, R22.2
unnamed: Q2.1 (B), R17.2
unnamed: Q2.3 (C), R18.2, R19.1
unnamed: C12.1, U6.6 (V3_{OUT})
unnamed: TP3.1, U6.12 (~DTR)
unnamed: R23.1, U6.13 (~RTS)
VBUS: C9.2, C10.2, C11.2, C13.2, D12.2 (K), Q2.2 (E), R16.2, R20.1, R22.1, U6.1 (VIO), U6.3 (VDD5), U6.9 (VBUS), U7.8 (VCC); also elsewhere on the board

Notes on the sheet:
See: https://emanual.robotis.com/docs/en/parts/interface/dynamixel_shield/ as a reference.
3A max
to grippers
Dynamixel RS485

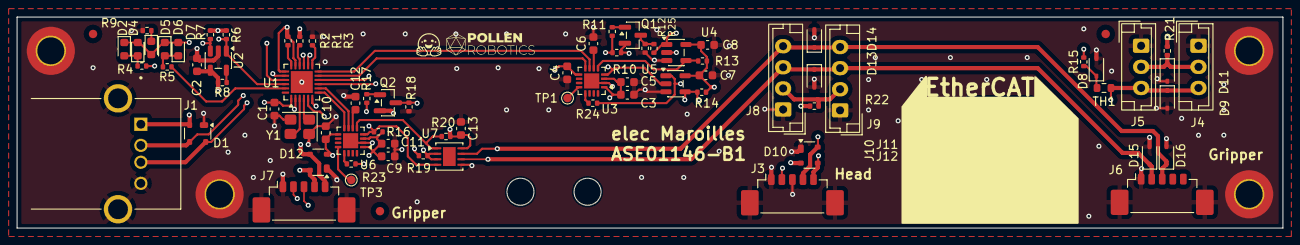
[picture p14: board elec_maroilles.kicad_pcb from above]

Board: 4 copper layers, 150.0 x 25.0 mm, 88 parts (0 on the bottom side), 55 nets.

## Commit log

2025-11-27 [init] Initial commit, schematic is not too bad.
    [dynamixel_3.kicad_sch, dynamixel_4.kicad_sch, elec_maroilles.kicad_pcb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]
2025-11-28 [update] Positionning v1
    [dynamixel_3.kicad_sch, dynamixel_4.kicad_sch, elec_maroilles.kicad_pcb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]
2025-12-02 [update] Better positionning.
    [elec_maroilles.kicad_pcb, elec_maroilles.kicad_sch, elec_maroilles.step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]
2025-12-02 [update] Release A1 -> in production at JLCPCB qtty 5
    [ASE01146-A1_elec_maroilles_STEP.step, dynamixel_3.kicad_sch, dynamixel_4.kicad_sch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]
2025-12-30 [error] To be fixed: inverted diff pairs on grippers pico5.
    [dynamixel_4.kicad_sch, elec_maroilles.kicad_sch]
2026-02-02 [update] Release B1!
    [dynamixel_3.kicad_sch, dynamixel_4.kicad_sch, elec_maroilles.kicad_pcb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]
